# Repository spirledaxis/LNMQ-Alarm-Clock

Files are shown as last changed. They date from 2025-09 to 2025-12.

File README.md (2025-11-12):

#  What is this?

This is a modified Lightning Mcqueen Alarm clock. It runs off a Pi Pico W. It's a sort of "smart" alarm clock. 

Original clock:

Note: for better cable management, I mounted the screen upside down. Thus, the display code assumes the origin in the bottom right corner, and has rotate=180 everywhere. (I didn't realize the library I was using can flip the display until it was too late)
## Features
-	2.42" OLED display with automatic timeout and diffrent states
    -   Home
    -   Set Alarm
    -   Message Viewer
    -   Display Off
-	TMP117 for ambient room temp.
-	Headlights (Synced to ringtones)
-	DFPlayer for any MP3 ringtone
-	Wifi
	-	NTP Time
	-	Messaging System
	-	Controls smart device
-   Battery Backup
-   JSON storage, retaining alarm time, messages, and ringtones upon reset/battery death

# Usage
While the code is made for this clock specifically, removing the headlights/motor portion of the code (or setting their pins to unused ones in config.py) will allow for an alarm clock with just a display, dfplayer/speaker, and buttons. There are only a some directories used by the clock in this repo (see uploading). 
You'll also need somewhere to run the discord bot in order for people to send messages to the clock. The clock can run without a server, but you lose the ability to send messages and caching, which allows for the clock to get messages even when offline (see Server section).

For music-synced LEDS, create a ``pulsepatterns`` dir on the pico. Upload pulsepatterns (created in audio dir) into that dir, naming them the index of the ringtone. To sync with 006.mp3, name it 6.json.

## Templates
alarm.json: quite straightforward. It is adjustable from the clock so you don't need to modify the file

motds.json: You may start with an empty list json '[]', then fill it up with the discord bot
-   Note: the 'time' key is currently not being used. It was intended to filter messages by how old they were, but I never coded that.
ringtones.json: Make sure this is synced with your DFplayer SD card. For example, if you have a Clash-Royale themed ringtone on 006.mp3 on the SD card:
```
{
    "index": 6,
    "description": "Clash Royale",
    "volume": 20
}
```
Volume is adjustable on the clock. Keep descriptions short so they are not cut off. When making the SD card, make a dir named ``01``, then sequentially number the ringtones. 
## Uploading
Use VScode with the micropico extension or mpremote. Upload the following:
-   .py files in the root dir
-   displaystates
-   hardware
-   lib
-   utils
-   alarm.json, motds.json, ringtones.json (upload into root dir)

#  Server

###  About

A Linux server is used in conjunction with the alarm clock (files that run on the server are in the server folder of the repo). This server hosts the discord bot, a message cache, and an http server to toggle the lights and interact with the server cache.

###  Why?

The alarm clock runs on micropython. This cannot support a discord bot nor the python-kasa library used to control the smart switch. Furthermore, if the alarm clock’s webserver isn’t online, then someone cannot send a message. Thus, a server cache is used. A Pi Zero could be used, but that isn’t breadboard friendly (gpios are all on one side). In addition, the linux overhead makes timing less precise, so the headlights wouldn't be synced as well.

#  Parts List

- SPI OLED (2.42” HiLetGo)

- DFPlayer

- L9110H

- PowerBoost 500C

- 1200mAh LiPo battery

- Pico WH

- Push buttons

- Speaker

- Solder breadboard

- Female pin headers

- NPN transistors

- White Leds x4 (high viewing angle)

- Boost converter (5 -> 9v)

- Resistors
#  Wiring:

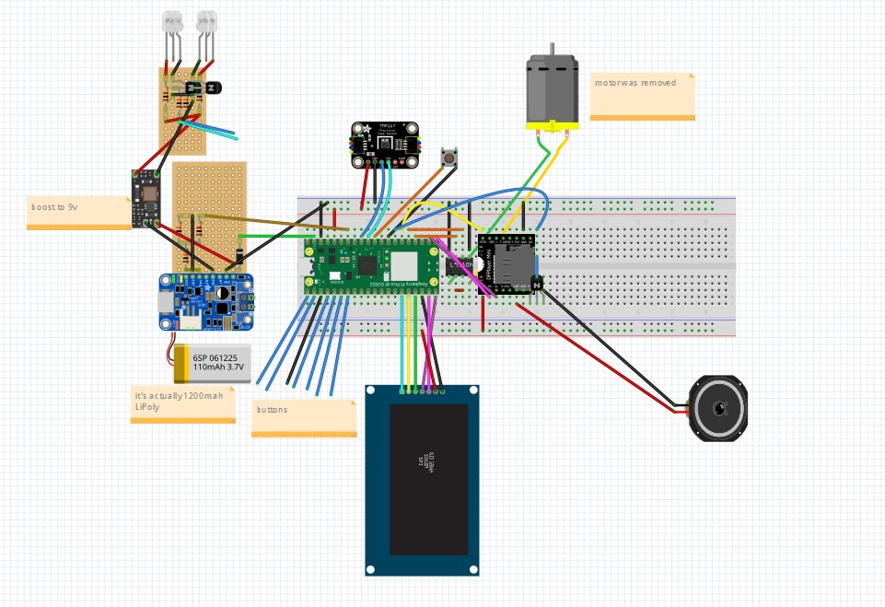
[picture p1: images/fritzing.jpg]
See the Fritzing sketch. (Fritzing file is also in the repo) 

#  Upgrades from original

- Membrane -> Tactile buttons

- Set any .mp3 file as ringtone

- Larger display

- LCD -> OLED

- Headlights

- Manual time setting -> NTP time

- Ambient temperature sensor

# Build




#  Kudos

Rdagger68 – Library for display and fonts, writeup example

Mannbro – Library for DFplayer

Jrullan – Library for Neotimer

Javl - https://javl.github.io/image2cpp/

AwDev - https://awdevsoftware.org/

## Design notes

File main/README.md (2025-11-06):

#  What is this?

This is a modified Lightning Mcqueen Alarm clock. It runs off a Pi Pico W. It's a sort of "smart" alarm clock. See before and after the modifications:
[insert images]
## Features
-	2.42" OLED display with automatic timeout
-	TMP117 for ambient room temp.
-	Headlights (Synced to ringtones)
-	DFPlayer for any MP3 ringtone
-	Wifi
	-	NTP Time
	-	Messaging System
	-	Controls smart device
-   Battery Backup
-   JSON storage in case clock dies

Note: for better cable management, I mounted the screen upside down. Thus, the display code assumes the origin in the bottom right corner, and has rotate=180 everywhere. (I didn't realize the library I was using can flip the display until it was too late)

#  Upgrades from original

- Membrane -> Tactile buttons

- Set any .mp3 file as ringtone

- Larger display

- LCD -> OLED

- Headlights

- Manual time setting -> NTP time

- Ambient temperature sensor

#  Server

###  About

A Linux server is used in conjunction with the alarm clock (files that run on the server are in the server folder of the repo). This server hosts the discord bot, a message cache, and an http server to toggle the lights and interact with the server cache.

###  Why?

The alarm clock runs on micropython. This cannot support a discord bot nor the python-kasa library used to control the smart switch. Furthermore, if the alarm clock’s webserver isn’t online, then someone cannot send a message. Thus, a server cache is used. A Pi Zero could be used, but that isn’t breadboard friendly (gpios are all on one side). In addition, the linux overhead makes timing less precise, so the headlights wouldn't be synced as well.

#  The original alarm clock

The orginal design had a pcb right behind the display and buttons that ran everything. There were only external wires for the batteries, motor, and speaker. I noticed these features

- Motor that can spin both ways, moving McQueen around (linearly)

- Transparent LCD display

- Buttons for control

- A switch to toggle the alarm

- Reset button

- Several power methods (Barrel jack, coin battery, 4xAA)

- Speaker

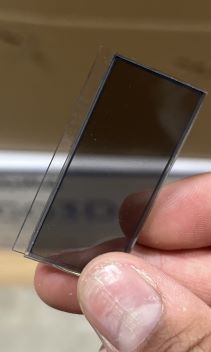
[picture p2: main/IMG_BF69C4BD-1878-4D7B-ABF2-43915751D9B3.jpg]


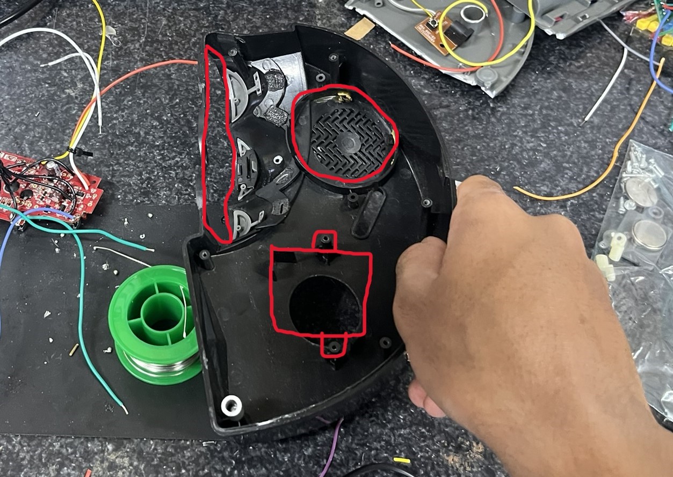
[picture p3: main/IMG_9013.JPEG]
The alarm clock appeared to have a ton of space on the inside, but there are ‘pillars’ that connect the bottom of the alarm clock to the body, reducing the amount of space to work with. The motor also took up a lot of space. I didn't take a picture with all the original components, so drew them on. You can see where the PCB, motor, and speaker sit. Power methods sat on the bottom plate. 

###  General Construction

The original PCB was used to keep buttons and switches in place. I ran wires from the buttons/switch to the pico.

The display sits left of the original display and is mounted far away from the clock body to allow McQueen to ~~move around~~. 3 nuts are used on each screw: one right behind the display (to hold it in place), and 2 on either side of the clock body. Using two screws allowed me to adjust how far out the display sits from the clock body.

The Pico and DFplayer are connected to the breadboard with female socket headers (H-bridge was directly soldered), and the breadboard sits behind the motor, and is secured via the top and bottom of the clock body.

I added an NPN transistor between the DFplayer and the speaker, as I noticed some feedback noise when the speaker was idle.

The Powerboost, Li-ion battery, and the boost converter are hot glued to the bottom plate. 

Each headlight consists of two LEDs in series, so the voltage must be >7V. Resistors were chosen for 9V, however, because I wanted the motor to run on 9v. The headlights have 4 wires: Vin, GND, and a signal wire for the left and right headlights. An NPN transistor is used for each headlight to toggle them. The leads of the LEDs were used for positioning and the protoboard was hot-glued in. I drilled a hole in the clock body for better cable routing.

The usb cable (not shown) comes out of what used to be the barrel jack hole. I modified the hole to stay continuous until the bottom, to have enough room for the cable. This cable is used for power and programming.

[add  images  in  this  section]

#  Compromises

These are things I wanted to add, but I couldn't for some reason.

- Custom PCB: Too many measurements and unknowns (such as hole radius for the screws) to create an accurate PCB that would fit in the footprint of the clock. I also wasn’t sure if all the components (pico, h bridge, DFplayer) would fit into the clock if I mount it where the original pcb was.

- Sound effects buttons (the smaller top buttons on the left and right) are linked, which gives a signal from both if one is pressed. I’d have to break a trace, then check if that stopped the linking. I have no idea which trace does that.

- No original sound effects: caused by poor planning, I didn’t record the clock’s factory sound effects before adding my modifications.

- Hard to repair design: mitigated by female pin headers on the board, but many things are directly soldered to each other. I didn't have connectors until recently.

- Can’t easily add ringtones: I need to open the clock to access the SD card and add more ringtones. Sd extender didn’t work, and mounting DFplayer and cutting a slit was too much work, as that would require extra wiring, 3d prints, and plastic cutting.

- Motor: The extra space and wiring from the powerboost and boost converter made it difficult for everything to fit inside. The headlights wiring also made McQueen significantly harder to move around, due to tension in the cable.
#  Parts List

- SPI OLED (2.42” HiLetGo)

- DFPlayer

- L9110H

- PowerBoost 500C

- 1200mAh LiPo battery

- Pico WH

- Push buttons

- Speaker

- Solder breadboard

- Female pin headers

- NPN transistors

- White Leds x4 (high viewing angle)

- Boost converter (5 -> 9v)

- Resistors
#  Wiring:

See the Fritzing sketch. (Fritzing file is also in the repo) 

#  Kudos

Rdagger68 – Library for display and fonts, writeup example

Mannbro – Library for DFplayer

Jrullan – Library for Neotimer

Javl - https://javl.github.io/image2cpp/

DanielNStovell - Rotating Cube

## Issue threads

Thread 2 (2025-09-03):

Motor out of sync

spirledaxis, 2025-09-03:
Motor cannot be reliably synced with the audio because it takes too long (~120ms) per tick. This causes the motor to not update fast enough.

Closed 2025-09-17.

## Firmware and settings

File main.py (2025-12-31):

import gc
import io
import json
import time

import machine  # type: ignore
from machine import RTC, Pin  # type: ignore

import config
import webserver

from bigicons import *
from displaystates import (DisplayOff, Home, MessageViewer, SetAlarm, aliases,
                           mode)
from hardware import display, headlights, motor, speaker
from lib import Neotimer, settime
from utils import (batstats, connect, fetch_cache, http_get, make_icon,
                   motd_parser, tempuratures)
from alarm import Alarm

# hello I am here to test the dev branch


try:
    alarm = Alarm(config.alarm_timeout_min * 60,
                motor, headlights, speaker)
    
    display.draw_sprite(make_icon(booticon, 128, 64), x=0, y=0, w=128, h=64)
    display.present()
    display_manager = mode.DisplayManager(alarm)
    home = Home(display_manager, aliases.home)
    setalarm = SetAlarm(display_manager, aliases.set_alarm)
    off = DisplayOff(display_manager, aliases.display_off)
    message_reader = MessageViewer(display_manager, home, aliases.message_reader)
    display_manager.display_states = [home, setalarm, off, message_reader]
    display_manager.set_active_state(aliases.home)
    display.set_contrast(0)

    rtc = RTC()
    now = rtc.datetime()
    print(now)
    print(machine.freq())

    wifi = connect.do_connect(3)
    print("are we connected?", connect.check_connection())
    if connect.check_connection() == True:
        settime()
        fetch_cache()
    else:
        display.draw_sprite(make_icon(booticon_warning, 128, 64), 0, 0, 128, 64)
        display.present()
        time.sleep(5)
        home.show_invalid_time = True
    s, clients = webserver.web_setup()

    prev_dur = 0
    loopcycles = 0
    lock_ntptime = False

    usb_power = Pin('WL_GPIO2', Pin.IN)
    usb_prev_state = None
    if usb_power.value() == 0:
        wifi.disconnect()
        wifi.active(False)

    while True:
        start = time.ticks_ms()
        displaytimer = time.ticks_ms()
        display_manager.run_current_state()
        display_elapsed = time.ticks_diff(time.ticks_ms(), start)
        now = rtc.datetime()

        # webserver
        webservertimer = time.ticks_ms()
        status = {
            "bell": -1,
            "wifi": -1,
            "battery": -1,
            "mail": home.iconactive_mail,
            "message": home.motd,
            "queue": home.new_motds
        }
        status = json.dumps(status)
        check = webserver.web_server(s, clients, status)
        if check is not None:
            if check[0] == 'motd':
                home.new_motds.append(check[1])
            elif check[0] == 'alarm_msg' and check[1] == 'random':
                with open('alarm.json', 'r') as f:
                    data = json.load(f)

                data['alarm_message'] = motd_parser.select_random_motd(home.motds_data)[
                    'motd']

                with open('alarm.json', 'w') as f:
                    json.dump(data, f)
            elif check[0] == "toggle_disp":
                if display_manager.current_state == aliases.home:
                    print("turning off from web")
                    display_manager.set_active_state(aliases.display_off)
                else:
                    print("turning on from web")
                    display_manager.set_active_state(aliases.home)
        webserver_elapsed = time.ticks_diff(time.ticks_ms(), webservertimer)

        # handle alarm
        if display_manager.alarm_active:
            alarm.update(now, home)

        # ntp
        hour = now[4]
        minute = now[5]
        if hour == 2 and minute == 1 and not lock_ntptime and connect.check_connection():
            lock_ntptime = True
            try:
                settime()
            except Exception:
                print("couldn't set the time via ntp")
            else:
                print("setting time via ntp and fetching cache")
            try:
                fetch_cache()
            except Exception:
                print("couldn't fetch the cache")
            else:
                print("fetched cache")

        elif minute != 1:
            lock_ntptime = False

        if usb_power.value() == 0 and usb_prev_state == 1:
            wifi.disconnect()
            wifi.active(False)
        elif usb_power.value() == 1 and usb_prev_state == 0:
            display.draw_sprite(make_icon(connecticon, 128, 64), x=0, y=0, w=128, h=64)
            display.present()
            connect.do_connect()
            

        usb_prev_state = usb_power.value()

        loopcycles += 1
        if loopcycles >= 50:
            loopcycles = 0
            gc.collect()

        # debug stuff
        dur = display_manager.display_timer.get_remaining()
        done = display_manager.display_timer.finished()
        cycle_time = time.ticks_diff(time.ticks_ms(), start)
        print(f"cycle: {cycle_time}, display: {display_elapsed}, web: {webserver_elapsed}, clock: {machine.freq()/1_000_000}, adc: {batstats.read_bat_voltage()}, mem: {gc.mem_free()/1000} KB, internal temp: {tempuratures.get_internal_temp()}", end="\r")
        home.looptime = cycle_time

except Exception as e:
    # TODO: add emergency alarm
    speaker.cleanup()
    motor.stop()
    import sys
    sys.print_exception(e)
    print("there was an error")
    try:
        print("attempting to connect to server to log error")
        buf = io.StringIO()
        sys.print_exception(e, buf)
        tb_str = buf.getvalue()
        tb_str = tb_str.replace(" ", "+")
        buf.close()
        status = http_get(config.server_ip,
                          config.server_port, f'/?error={tb_str}')
        print(status)
        if status == 'Error recieved':
            print("server recived the error")
    except BaseException:
        print("could not log to server, it'll be saved on the pico")

    finally:
        with open('errors.txt', 'a') as f:
            sys.print_exception(e, f)
            f.write(f'\n{rtc.datetime()}\n')

        print("saved error to pico")


    display.draw_sprite(make_icon(failicon, 128, 64), x=0, y=0, w=128, h=64)
    display.present()
    timer = Neotimer(config.bsod_timeout_s * 1000)
    timer.start()

    while not timer.finished():
        time.sleep_ms(100)

finally:
    print("doing cleanup")
    speaker.cleanup()
    display.cleanup()
    motor.stop()
    headlights.stop()
    stop_threads = True
    print("cleanup success!")

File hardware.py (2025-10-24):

from lib.neotimer import Neotimer
from machine import Pin, PWM  # type: ignore
from lib.neotimer import Neotimer
import json
from lib import timeutils
from utime import sleep_ms
from movements import *
import errno
from time import sleep_us
import _thread
class Motor:
    def __init__(self, left_pin, right_pin, pwm_freq, min_pwm):
        "cmd sytax: ('dir', time_ms, %speed)"
        self.left_pin = PWM(Pin(left_pin), pwm_freq, duty_u16=0)
        self.right_pin = PWM(Pin(right_pin), pwm_freq, duty_u16=0)
        self.is_idle = True
        self.ready = False
        self.movement_increment = -1
        self.timer = Neotimer(0)
        self.min_pwm = min_pwm
        self.max_pwm = 65535
        self.repeat = False

    def _interact(self, cmd, speed_percent):
        # speed to duty cycle (speed param is percentage)
        speed_percent = max(0, min(speed_percent, 100))
        # Linear interpolation
        duty_cycle = int(self.min_pwm + (speed_percent / 100)
                         * (self.max_pwm - self.min_pwm))

        if cmd == 'l':
            self.left_pin.duty_u16(duty_cycle)
            self.right_pin.duty_u16(0)
        elif cmd == 'r':
            self.left_pin.duty_u16(0)
            self.right_pin.duty_u16(duty_cycle)
        elif cmd == 'w':
            self.left_pin.duty_u16(0)
            self.right_pin.duty_u16(0)

        self.is_idle = False

    def set_movement(self, movement):
        """A movement is a list of tuples.
        Syntax: (cmd, dur_ms, speed)
        cmd: 'l', 'r', or 'w' (wait)
        dur_ms: duration of that cmd
        speed: a percent of the motors speed
        """
        self.movement = movement
        self.timer.start()

    def do_movement(self):
        if not self.ready:
            return

        if self.timer.finished():
            if self.movement_increment + 1 >= len(self.movement):
                print("end of movement")
                if not self.repeat:
                    self.stop()
                self.movement_increment = -1

            else:
                self.movement_increment += 1
                cmd, dur_ms, speed = self.movement[self.movement_increment]
                self.timer = Neotimer(dur_ms)
                self.timer.start()
                self._interact(cmd, speed)

    def motor_thread_step(self):
        if self.ready:
            self.do_movement()

    def movement_len_ms(self, movement):
        time_ms = 0
        for _, dur_ms, _, in movement:
            time_ms += dur_ms

        return time_ms

    def stop(self):
        print("stopping motor")
        self.left_pin.duty_u16(0)
        self.right_pin.duty_u16(0)
        self.is_idle = True
        self.ready = False
        self.timer = Neotimer(0)
        self.timer.start()
        self.movement_increment = -1

    def start(self, reset_increment=False):
        self.ready = True
        if reset_increment:
            self.movement_increment = -1

    def set_movement_by_ringtone(self, ringtone):
        self.repeat = False
        if ringtone == 13:
            self.set_movement(freedom_dive)
        elif ringtone == 8:
            self.set_movement(i_am_speed)
        elif ringtone == 19:
            self.set_movement(eta)
        elif ringtone == 17:
            self.set_movement(stay_with_me)
        elif ringtone == 18:
            self.set_movement(clash_royale)
        else:
            self.set_movement(default)
            self.repeat = True
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

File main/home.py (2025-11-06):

import errno
import json
import time

import framebuf  # type: ignore
import network  # type: ignore
from machine import RTC, Pin  # type: ignore

import config
from hardware import Button
from lib import Neotimer, ntptime
from utils import (batstats, make_icon, motd_parser, tempuratures, timeutils,
                   toggle_smartswitch)

from . import aliases
from .fonts import bally, bally_mini, timefont
from .mode import DisplayState


class Home(DisplayState):
    def __init__(self, display_manager, name):
        self.button_map = [
            Button(config.alm_set, self.on_alm_set),
            Button(config.snze_l, self.on_snze),
            Button(config.fwd, self.on_fwd),
            Button(config.rev, self.on_rev),
            Button(config.snd_fx_l, self.on_snd_sfx),
            Button(config.clk_set, self.on_clk)
        ]
        super().__init__(self.button_map, name, display_manager)
        self.display_manager = display_manager
        self.motd = ''
        self.prev_motd = ''
        self.motd_dir = 'l'
        self.motd_mode = 'scroll'
        self.bounce_firstime = True

        with open('motds.json', 'r') as f:
            motds_data = json.load(f)
        self.motds_data = motds_data
        self.new_motds = []
        self.reset_motd()
        for motd_json in motds_data:
            if motd_json['new'] is True:
                print('found an new motd')
                print('appending', motd_json)
                self.new_motds.append(motd_json)
                print('new motds', self.new_motds)

        self.usb_power = Pin('WL_GPIO2', Pin.IN)
        self.rtc = RTC()
        self.alarm = display_manager.alarm
        self.time_len = 0

        self.bell_icon_fb = make_icon(
            [0x03, 0x0c, 0x10, 0xe1, 0xe1, 0x10, 0x0c, 0x03])
        self.bell_icon_off = make_icon(
            [0x03, 0x0d, 0x13, 0xe6, 0xec, 0x18, 0x3c, 0x23])
        self.snooze_icon = make_icon(
            [0xc1, 0xe1, 0xf1, 0xb9, 0x9d, 0x8f, 0x87, 0x83])
        self.plug_icon = make_icon(
            [0x00, 0x10, 0xf8, 0x1f, 0x1f, 0xf8, 0x10, 0x00])
        self.battery_icon = make_icon(
            [0x00, 0x3f, 0x21, 0xe1, 0xe1, 0x21, 0x3f, 0x00])
        self.wifi_icon = make_icon(
            [0x00, 0xff, 0x00, 0x3f, 0x00, 0x0f, 0x00, 0x03])
        self.no_wifi_icon = make_icon(
            [0x00, 0xff, 0x00, 0x3f, 0x00, 0xaf, 0x40, 0xa3])
        self.mail_icon = make_icon(
            [0xff, 0xa1, 0x91, 0x8d, 0x8d, 0x91, 0xa1, 0xff])
        self.sleep_icon = make_icon(
            [0x40, 0x20, 0x42, 0x05, 0x42, 0x20, 0x40], 7, 7)
        self.degree_symbol = make_icon([0x02, 0x05, 0x02], 3, 3)

        self.blink_wifi_max = config.blink_wifi_max
        self.blinked_wifi = 0
        self.blink_wifi = False
        self.blink_wifi_inverval = Neotimer(config.blink_nowifi_ms)

        self.looptime = 0
        self.offset_val = -6
        self.offset = 0
        self.apply_offset = False

        self.iconactive_bell = False
        self.iconactive_wifi = False
        self.iconactive_battery = False
        self.iconactive_mail = False
        self.v_battery = 0

    def on_rev(self):
        if self.motd_mode == 'scroll':
            with open('alarm.json', 'r') as f:
                data = json.load(f)
                self.motd = data['alarm_message']
                self.motd_mode = 'bounce'
        elif self.motd_mode == 'bounce':
            self.motd = motd_parser.select_random_motd(self.motds_data)['motd']
            self.motd_mode = 'scroll'

    def on_alm_set(self):
        self.blink_wifi = False
        self.blinked_wifi = 0
        self.display_manager.set_active_state(aliases.set_alarm)

    def on_snd_sfx(self):
        if self.alarm.is_active:
            self.alarm.stop()
            self.motd = motd_parser.select_random_motd(self.motds_data)['motd']
            self.motd_mode = 'scroll'
        else:
            self.blink_wifi = False
            self.blinked_wifi = 0
            self.display_manager.set_active_state(aliases.display_off)

    def on_fwd(self):

        if len(self.new_motds) == 0:
            self.motd_pos += config.scroll_on_fwd
            self.motd_pos_noadj += config.scroll_on_fwd
        else:
            print("reading message")
            with open('motds.json', 'r') as f:
                all_motds = json.load(f)

            for motd in all_motds:
                # set the read motd to new: false
                if motd['id'] == self.new_motds[0]['id']:
                    print(motd, motd['id'], self.new_motds[0])
                    print("marked motd as read")
                    motd['new'] = False
                    break
            else:
                raise ValueError(
                    "something went wrong when reading the message")

            motd = self.new_motds[0]
            motd = f"{motd['motd']} @{motd['author']}"

            self.reset_motd(motd)
            self.new_motds.pop(0)

            # update the json file so it says new: false
            with open('motds.json', 'w') as f:
                json.dump(all_motds, f)

            # then, reload the data
            with open('motds.json', 'r') as f:
                self.motds_data = json.load(f)

    def on_snze(self):
        if self.alarm.is_active:
            self.alarm.stop(False)
            self.alarm.snooze()
            self.blink_wifi = False
            self.blinked_wifi = 0
            self.display_manager.set_active_state(aliases.display_off)

        else:
            print("turning off light")
            try:
                toggle_smartswitch()
            except OSError as e:
                if e.errno == errno.EHOSTUNREACH:
                    self.blink_wifi = True
                else:
                    raise

    def on_clk(self):
        print("switching state")
        self.blink_wifi = False
        self.blinked_wifi = 0
        self.display_manager.set_active_state(aliases.message_reader)

    def clock(self):
        now = self.rtc.datetime()
        month = now[1]
        month_day = now[2]
        day_name_int = now[3]
        hour = now[4]
        minute = now[5]
        second = now[6]

        hour_ampm, _ = timeutils.convert_to_ampm(hour)
        time_text = f'{hour_ampm}:{minute:02}'
        self.time_len = timefont.measure_text(time_text)

        self.time_len = timefont.measure_text(time_text)
        date_text = f'{timeutils.daynum_to_daystr(day_name_int)} | {timeutils.monthnum_to_monthstr(month)} {month_day}'
        date_text_len = bally.measure_text(date_text)
        if date_text_len >= 128:
            date_text = f'{timeutils.daynum_to_daystr(day_name_int)} | {timeutils.monthnum_to_monthabbr(month)} {month_day}'
            date_text_len = bally.measure_text(date_text)

        # origin is in the bottom right
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

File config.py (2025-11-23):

# motor
motor_l = 19
motor_r = 18
motor_pwm_freq = 20_000
motor_min_pwm = 37_000


# headlights
headlight_l = 22
headlight_r = 3
headlights_pwm_freq = 1000
max_brightness = 1  # value from 0 to 1

# dfplayer
rx = 17
tx = 16
transistor = 21
busy = 20
uarto_channel_df = 0


# display
"""
pins from gnd-cs
gnd
vcc
sck
sda
res
dc
cs
"""
sck = 14
sda = 15
res = 13
dc = 12
cs = 11
spi_channel_disp = 1


# temperature
tmp_scl = 27
tmp_sda = 26

# inputs
snd_fx_l = 8  # these are also paired
snd_fx_r = 2  # right wire fell off, idc enough to solder it on. Thus, use the left one
snze_l = 4  # the snze buttons seems to be paired
snze_r = 3  # so, you can use either (but not both!)
alm_set = 0
clk_set = 1
fwd = 7
rev = 9
switch = 6

# timers
display_timeout_min = 10
display_messenger_timeout_min = 360
messenger_cycle_time_s = 30
messenger_icon_invert_time_s = 10
messenger_drift_inverval_ms = 15_000
alarm_timeout_min = 5
bsod_timeout_s = 15
blink_nowifi_ms = 200

# ips
server_ip = '192.168.1.21'
server_port = 8080

# other
blink_wifi_max = 5
sleep_offset_min = 20
bat_adc = 28
msg_scroll_speed = 1
snooze_min = 10
scroll_on_fwd = 64
first_of_month_index = 25

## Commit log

2025-08-03 bugfixes + ringtone support
    [bot.py, components.py, config.py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]
2025-08-06 Idk what to call this commit
    -Motor: edited class to work as intended
    -Bot: added illegal character filter
    -Removed bally mini
2025-08-07 Bot and logic fixes
    [bot.py, main.py, motds_backup.py]
2025-08-08 fixed alarm bugs
    -Screen would turn off early
    -Indexing used the wrong variable
    [main.py]
2025-08-09 server reformatting, synced motor movements, kasa switch support
2025-08-27 bugfixes and server caching
    [bot.py, components.py, config.py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]
2025-08-30 remove print statements
2025-09-01 moved button and switch to DisplayManager
2025-09-01 motor moved to config
2025-09-01 fix display timeout bug
    [mode.py]
2025-09-06 add midpoint and hold button logic
2025-09-06 add fritzing to repo
    [alarm clock project.fzz]
2025-09-06 add pushbutton to fritzing
    [alarm clock project.fzz]
2025-09-07 fix alarm not going off
    [components.py]
2025-09-09 motor uses threading for better sync
2025-09-12 better motor sync
2025-09-13 battery icon blinks
2025-09-13 battery blink + drifting
    [messageviewer.py]
2025-09-14 hardware and alarm seperated; set_movement_by_ringtone moved to inside motor
2025-09-14 add warning if caches fail
    [main.py]
2025-09-14 add on battery behaviour
2025-09-14 turn off wifi when it runs on battery
2025-09-14 remove battery display timer cuz I cant get it to work :(
2025-09-15 constants added so text doesn't jitter
    [setalarm.py]
2025-09-21 dont have a printer
2025-09-22 Add alarm message preview with rev button Fetch cache daily
2025-09-22 fetch cache every night and a bundle of fixes
    [main.py]
2025-10-11 add predicted sleep and ms/frame to display
2025-10-11 Add status.json vars and a bundle of fixes
    [home.py]
2025-10-11 add wires to buttons and headlight hardware
    [alarm clock project.fzz]
2025-10-13 add /?=error, allows clock to send its errors to the server
    [webserver.py]
2025-10-18 remove delays in thread step
    Headlights: Add default pattern
2025-10-20 add battery icons
2025-10-20 read bat voltage
2025-10-24 remove switch
2025-10-24 Add HeadlightsStream and move thread to headlights class
    HeadlightsStream streams the json file rather than load all of it at once.
    Thread now only starts when headlights are active
2025-10-24 fix battery sprite flickering while active, scroll speed controlled by config
    [home.py]
2025-10-24 remove motor preview and change to config headlights
2025-10-24 update to current hardware
    Notably, adds headlights and boost converter
    [alarm clock project.fzz]
2025-10-24 update to current hardware
2025-10-24 snooze icon is now oriented correctly
    [home.py]
2025-10-25 snooze is controlled by config; stop method has new arg to reset to normal alarm time
    [alarm.py]
2025-10-25 Fix display turning off when stopping alarm
    [home.py]
2025-10-25 add usb wiring
    [alarm clock project.fzz]
2025-10-28 move battery icons to batstats
    Rename batvoltage -> batstats
    Move icon logic into batstats
2025-10-30 add button repitition for selection
2025-11-02 remove dubug print
2025-11-02 adjust voltages according to adafruit
    https://learn.adafruit.com/assets/979 using 0.2C
2025-11-06 won't attempt wifi things if it can't connect to wifi
    [main.py]
2025-11-06 fix icons and add delay upon failure
    [fetch_cache.py]
2025-11-06 use make icon instead of framebuf
2025-11-06 Move main branch files into main/ dir
    [alarm clock project.fzz]
2025-11-06 Fix the repo
    I don't like branches very much... What the hell?
    [alarm clock project.fzz]
2025-11-11 remove comments/prints
2025-11-22 draw failicon instead of booticon warning upon failure
    [main.py]
2025-11-23 A couple changes
    -Padded looptime
    -Shows temp/sleep based on alarm active
    -Don't show a bell if alarm is off
2025-12-31 fix transition from off to home
    [display_off.py, mode.py]
2025-12-31 fix battery icon tweaking out
    [display_off.py]
2026-01-17 fix logic bug with displaying the time
    [home.py]
2026-01-17 temp is permanent now, sleep/tick is the one to switch
